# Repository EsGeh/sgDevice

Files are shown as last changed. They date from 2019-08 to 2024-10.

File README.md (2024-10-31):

# sgDevice

*sgDevice* is a MIDI interface that can send and receive MIDI messages to/from a computer via USB.
It has a knobs, switches and triggers. The state of these controls is reported to the connected computer.
It may therefore be used as an input device to control *any kind* of software that receives MIDI messages - there is no intrinsic audio related functionality.
sgDevice (ver. 2) uses the [Arduino](https://www.arduino.cc/) Mega microprocessor board.

This repository contains:

- Basic information about *sgDevice*, a homemade MIDI device

- A software library for the [puredata](https://puredata.info/) music software that enables puredata patches to react to messages from the sgDevice. This allows a pd patch to e.g. play notes when a trigger is pressed or updating an effect parameter based on a knob position

- Tools and utility scripts to compile and upload the firmware to the sgDevice

## Pictures

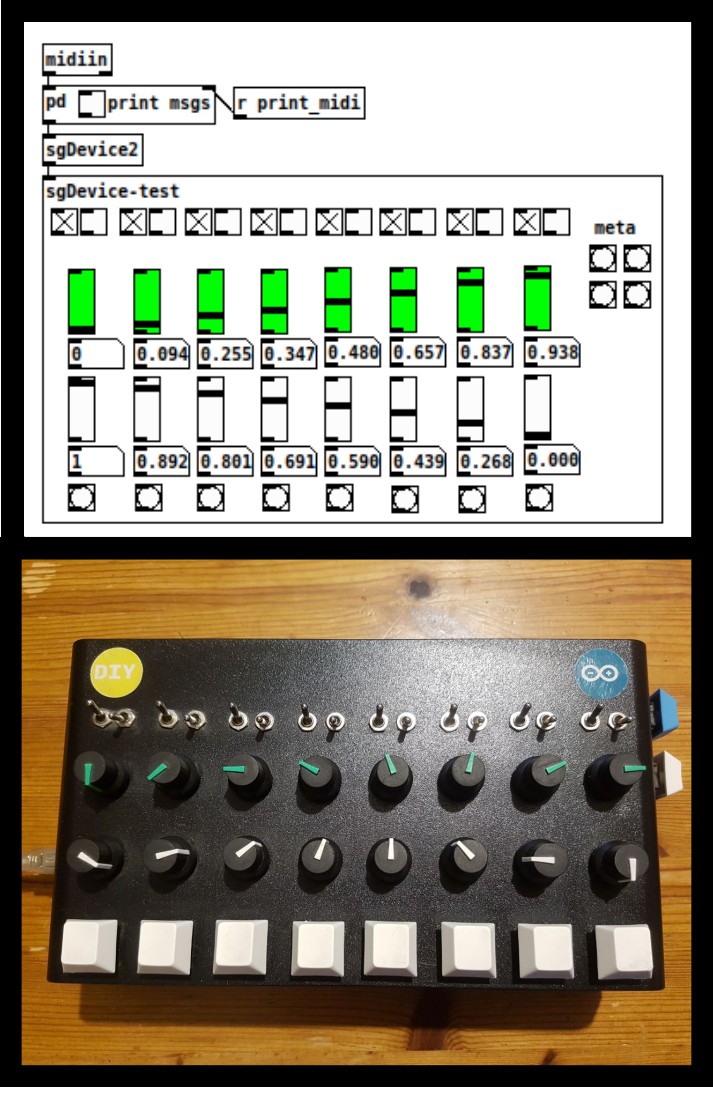
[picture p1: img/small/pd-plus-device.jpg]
pd plus device

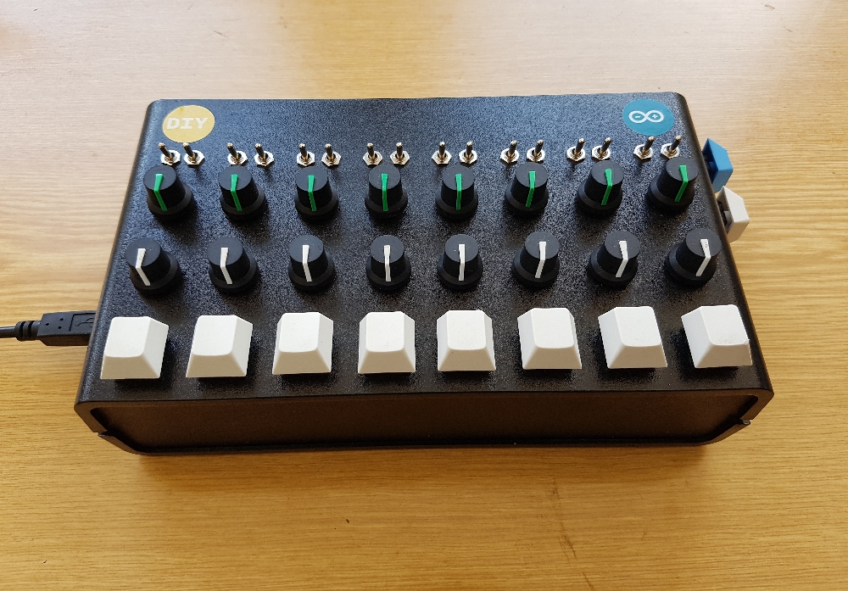
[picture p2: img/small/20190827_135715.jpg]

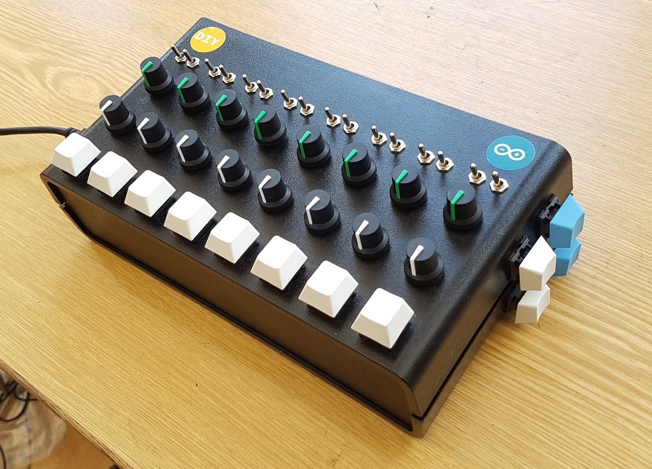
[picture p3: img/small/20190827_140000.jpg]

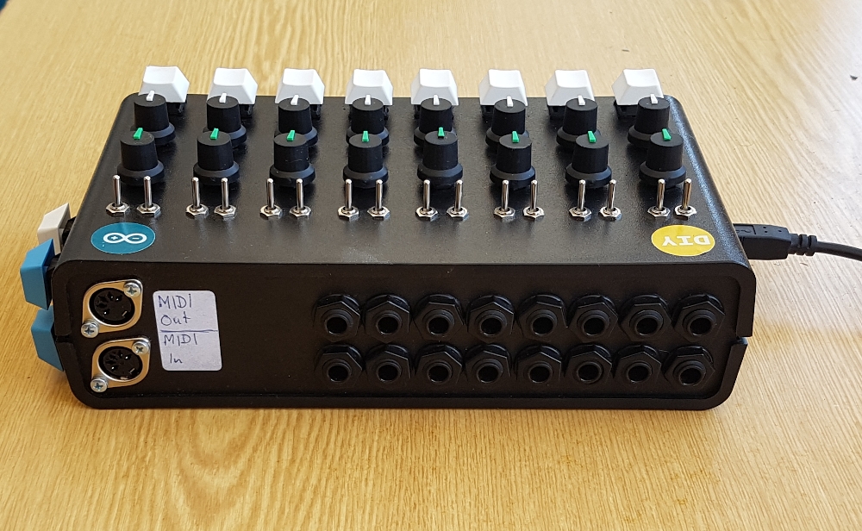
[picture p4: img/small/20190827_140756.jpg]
sgDevice ver 2, backside

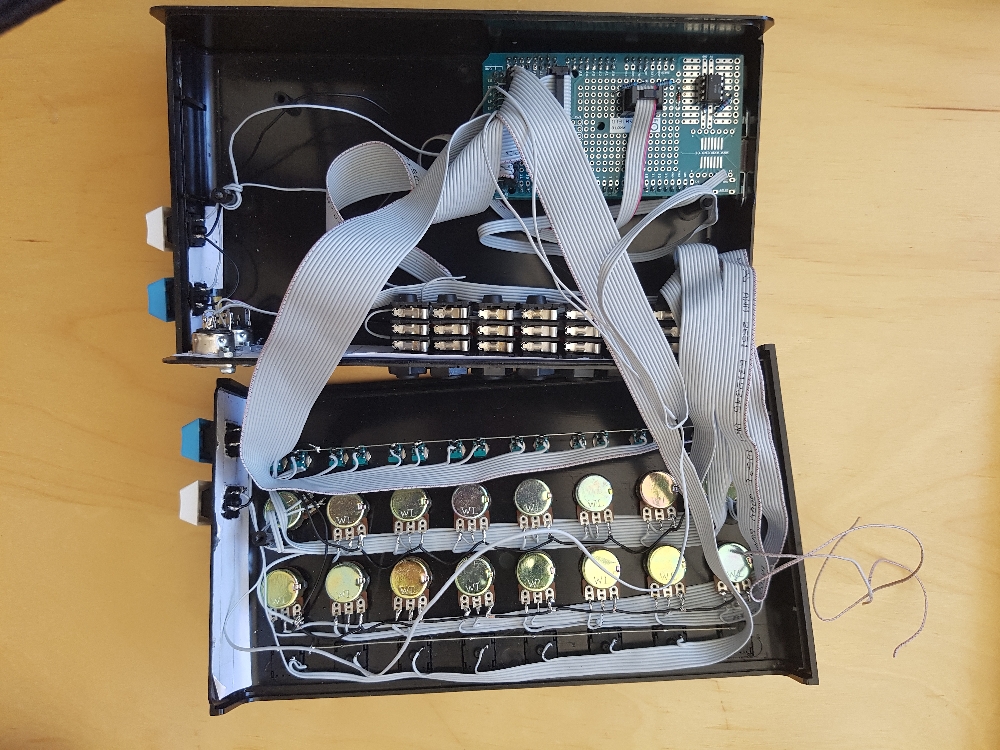
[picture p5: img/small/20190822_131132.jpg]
sgDevice ver 2, interior


## Demos

[Dark Ambient Music with Puredata+sgDevice2](https://youtube.com/watch?v=bEVVliKHZgQ):

Dark Ambient Music with Puredata+sgDevice2 (https://youtube.com/watch?v=bEVVliKHZgQ)

## Prerequisits

- [fish shell](https://fishshell.com/)

## Project setup

- Initialise project (download dependencies, ...):

		$ ./scripts/init.fish
	
	This will download and git dependencies into `./dependencies/`

- Clean project

		$ ./scripts/exit.fish

# Build and upload Firmware

## Build Dependencies

- [arduino-cli](https://github.com/arduino/arduino-cli)
- ( legacy) `arduino`: only for sgDevice1

## sgDevice2

- Turn the Arduino into a native MIDI device:

    The case has to be open in order to set a jumper.
    This (hopefully) has only to be done once!

    plug the device in the PC via USB, then run:

        $ ./scripts/arduino_upload_usb_firmware.fish

    The script will guide you

- Set midi device name:

    plug the device in the PC via USB, then run:

        $ ./scripts/midi_set_device_name.fish

## sgDevice1 (legacy)

Plug the device in the PC via USB, then run:

    $ ./scripts/arduino_upload.fish

The script will guide you

# Build and install the Puredata Library for sgDevice

## Prerequisits

- [puredata](https://puredata.info/): the famous computer music software

## Test locally without installing to system

1. Install library to a local dir

		$ ./scripts/local_init.fish

2. Run Example

		$ ./scripts/local_run.fish

	This opens an example patch documenting the major parts of this library.

3. Uninstall library from the local dir

		$ ./scripts/local_exit.fish

## Installation

- Build and install:

        $ ./scripts/build.fish install

    (for options append `--help`)

- Configure pd to load the library

	start pd and add `structuredDataC` under `File -> Settings -> Start -> New`

- Configure pd to find abstractions

	start pd and add `<install_location>/structuredDataC` under `File -> Settings -> Path -> New`

- Make sure the [dependencies](#dependencies) are installed. Please refer to the corresponding documentation of these libraries.

## Dependencies

- [structuredData](https://github.com/EsGeh/structuredData): Utiliy library for puredata
- [zexy](https://git.iem.at/pd/zexy)

## Documentation

The Documentation is provided as puredata example patches accessible in pd under `Help -> Patch Browser -> structuredDataC`.
Alternatively, for help with a specific object, right click on it and select "help".

# Wiring Schema

sgDevice 2 wiring schema

# Testing and Debugging

## sgDevice2 - Test native Midi Device

	$ ./scripts/local_init.fish
	$ ./scripts/local_run.fish --debug

Check `./logs/` directory afterwards

## sgDevice1 - Test USB input (legacy)

	$ ./scripts/arduino_usbdump.fish

# References

- MIDI Specification:

	- <http://midi.teragonaudio.com/tech/midispec.htm>

- [USBMidiKliK](https://github.com/EsGeh/USBMidiKliK.git):

	Turn the Arduino into a native MIDI Device.

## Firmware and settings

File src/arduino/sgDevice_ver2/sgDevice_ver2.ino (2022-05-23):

#include "Constants_ver2.h"

/*
	NOTES:
	Messages from MIDI-IN are directly sent to the pc.
	Messages from PC are directly sent to MIDI-OUT.
*/

//#define DEBUG_PRINT
#ifdef DEBUG_PRINT
#undef PC_RATE
#define PC_RATE 9600
#endif


class Analog
{
	private:
		int analog[ANALOG_COUNT];
	public:
		Analog()
		{
			for(int i=0; i<ANALOG_COUNT; i++)
			{
				//analog[i] = 0;
				analog[i]= analogRead(i);
			}
		};

		void setup()
		{
		}

		// send all current values:
		void sendAll()
		{
			for(int i=0; i<ANALOG_COUNT; i++)
			{
				toPC(i);
			}
		}

		void update()
		{
			for( int i=0; i<ANALOG_COUNT; i++)
			{
				int newVal = analogRead(i);
				if (abs(newVal-analog[i]) >= 2 )
				{
					analog[i]=newVal;
					toPC(i);
				}
			}
		}

		void toPC(int i)
		{
			#ifdef DEBUG_PRINT
				//Serial.println( analog[i] );
				Serial.print( "Analog value [" );
				Serial.print( i );
				Serial.print( "]: " );
				Serial.println( analog[i] );
			#else
				#ifndef ANALOG_DOUBLE_PRECISION
					Serial.write( 0xB0 );
					Serial.write( ANALOG_CONTROL_ID + i );
					Serial.write( analog[i] );
				#else
					byte msb = analog[i] >> 3;
					byte lsb = analog[i] & 0b00000111;
					Serial.write( 0xB0 );
					Serial.write( ANALOG_CONTROL_ID + i);
					Serial.write( msb);
					Serial.write( 0xB0 );
					Serial.write( ANALOG_CONTROL_ID_FINE + i );
					Serial.write( lsb );
				#endif
			#endif
		}
};

class Buttons
{
	// values
	private:
		unsigned int pin0;
		unsigned int count;
		unsigned int control_id;
		boolean invert;
	public:
		boolean* value;
	// methods:
	public:
		Buttons(
			const unsigned int pin0,
			const unsigned int count,
			const unsigned int control_id,
			const bool invert = false
		)
			:pin0(pin0),
			count(count),
			control_id(control_id),
			value(NULL),
			invert(invert)
		{
			value = new boolean[count];
			for (int i=0; i<count ; i++)
			{
				value[i]=false;
			}
		}
		~Buttons() {
			delete[] value;
		}
		void setup()
		{
			for( int i=0; i<count; i++ )
			{
				pinMode(pin0+i, INPUT_PULLUP);
			}
		}
		// overwrite:
		void OnChange(const unsigned int index, boolean newValue) { }
		void update()
		{
			for (int i=0; i< count ; i++)
			{
				bool new_val = digitalRead(pin0+i);
				bool logical_value =
					(!invert) ? new_val : (!new_val);
				if( logical_value != value[i])
				{
					value[i] = logical_value;
					#ifdef DEBUG_PRINT
						Serial.println(String("Buttons[") + String(pin0+i) + String("] = ") + String((unsigned int )logical_value));
					#else
						Serial.write( 0xB0 );
						Serial.write( control_id + i );
						Serial.write( ((byte )127) * ((byte )logical_value));
					#endif
				}
			}
		}
};

class Midi
{
	private:
		byte buf[6];
		int buf_count;
	public:
	Midi()
		: buf_count(0)
	{
	}

	void setup()
	{
	}

	// MIDI-In -> PC
	void update_midi_in()
	{
		int input = -1;
		if( Serial1.available() > 0 ) {
			input = Serial1.read();
			if( input >= 0x80 ) {
			// status byte:
				// only send "note on" or "note off" msgs
				// (ignore others):
				byte msg_type = input >> 4;
				byte channel = input & 0b00001111;
				if(
					 msg_type == 0x8
					 || msg_type == 0x9
				)
				{
					// increase channel:
					buf[0] = input;
					buf_count = 1;
				}
				else
				{
					// ignore:
					buf_count = 0;
				}
			}
			else
			// data byte:
			{
				if( buf_count > 0 && buf_count < 3 )
				{
					buf[buf_count] = input;
					buf_count ++;
				}
				if( buf_count >= 3 )
				{
					for( int i=0; i<buf_count; i++ )
					{
						Serial.write( buf[i] );
					}
					Serial.flush();
					buf_count = 0;
				}
			}
			/*
			// filter out "timing" and "Active Sensing" input:
			if( input != 0b11111000 && input != 0b11111110 )
			{
				#ifdef DEBUG_PRINT
				//Serial.println( analog[i] );
				Serial.print( "MIDI->PC: " );
				Serial.println( input, HEX);
				#else
				Serial.write( (byte )input );
				Serial.flush();
				#endif
			}
			*/
		}
	}

	// PC -> MIDI-Out
	void update_midi_out()
	{
		int input = -1;
		if( Serial.available() > 0 )
		{
			input = Serial.read();
			#ifdef DEBUG_PRINT
				Serial.print( "PC->MIDI: " );
				Serial.println( input );
				Serial1.write( 0x90 );
				Serial1.write( 60 );
				Serial1.write( 100 );
			#else
				Serial1.write( input );
			#endif
			Serial1.flush();
		}
	}
};

Analog analog;
Midi midi;
Buttons switches(
	PIN_SWITCH,
	SWITCHES_COUNT,
	SWITCHES_CONTROL_ID
);
Buttons triggers(
	PIN_TRIGGERS,
	TRIGGERS_COUNT,
	TRIGGERS_CONTROL_ID,
	true // invert
);
Buttons meta(
	PIN_META,
	META_COUNT,
	META_CONTROL_ID,
	true // invert
);

void setup() {
	Serial.begin(PC_RATE);
	Serial1.begin(MIDI_RATE);

	//sleep(2);

	analog.setup();
	midi.setup();
	switches.setup();
	triggers.setup();
	meta.setup();

	#ifdef DEBUG_PRINT
	Serial.println("initializing");
	#endif
}

//Message

void loop() {
	analog.update();
	midi.update_midi_in();
	midi.update_midi_out();
	switches.update();
	triggers.update();
	meta.update();
}

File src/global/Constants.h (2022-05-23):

#ifndef _CONSTANTS_H_
#define _CONSTANTS_H_


/////////////////////////////
// baud rates:
/////////////////////////////
#define MIDI_RATE 31250
//#define PC_RATE 9600
#define PC_RATE 38400

/////////////////////////////
// control id in MIDI messages:
/////////////////////////////

#define TRIGGERS_CONTROL_ID (32+0)
#define SWITCHES_CONTROL_ID (32+10)
#define ANALOG_CONTROL_ID 20
#define ANALOG_CONTROL_ID_FINE (32+20)
#define META_CONTROL_ID 64

/////////////////////////////
// arduino pins
/////////////////////////////

#define PIN_MIDI_IN 2
#define PIN_MIDI_OUT 3

#define PIN_META_TRIGGER_0 11
#define META_COUNT 2

#define PIN_TRIGGER_OR_SWITCH 10
#define TRIGGERS_COUNT 6
#define SWITCHES_COUNT 6
#define PIN_TOG_0 4

#define TRIGGER_PRESSED 0
#define DEBOUNCE_TIME 200

// which value means
#define TRIGGERS 1


/////////////////////////////
// analog parameters:
/////////////////////////////

#define ANALOG_COUNT 6
#define ANALOG_STEPS 512

// maximum value at analog pins:
#define ANALOG_PIN_BITS 10
#define ANALOG_PIN_RESOLUTION (1<<ANALOG_PIN_BITS)

// if defined: use 2 midi messages to use 14 bytes instead of 7 bytes
// define this, if you want more than ANALOG_STEPS > 128

#define ANALOG_DOUBLE_PRECISION 1

#endif

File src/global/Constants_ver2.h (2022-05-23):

#ifndef _CONSTANTS_H_
#define _CONSTANTS_H_


/////////////////////////////
// baud rates:
/////////////////////////////
#define MIDI_RATE 31250
#define PC_RATE 31250
// (according to MIDI specification)

/////////////////////////////
// control id in MIDI messages:
/////////////////////////////

#define ANALOG_CONTROL_ID 0
#define ANALOG_CONTROL_ID_FINE 32
/* midi control numbers 32..31:
 if ANALOG_DOUBLE_PRECISION is defined,
 these may specify the
 least significant bits (LSB) of
 the controls 0..31.
*/

#define ANALOG_COUNT 16

#define SWITCHES_CONTROL_ID (32+16)
#define SWITCHES_COUNT 16

#define TRIGGERS_CONTROL_ID 64
#define TRIGGERS_COUNT 8

#define META_CONTROL_ID 96
#define META_COUNT 4

/////////////////////////////
// arduino pins
/////////////////////////////

#define PIN_SWITCH 22
#define PIN_TRIGGERS 38
#define PIN_META 46

/////////////////////////////
// analog parameters:
/////////////////////////////

#define ANALOG_MIDI_RES 512
#define ANALOG_STEPS 512

// maximum value at analog pins:
#define ANALOG_PIN_BITS 10
#define ANALOG_PIN_RESOLUTION (1<<ANALOG_PIN_BITS)

// if defined: use 2 midi messages to use 14 bytes instead of 7 bytes.
// uncomment, if you want more than ANALOG_STEPS > 128:
#define ANALOG_DOUBLE_PRECISION

#endif

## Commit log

2019-05-11 dummy code for the new sgDevice2. arduino-cli for compilation, upload.
2019-05-11 added Frizzing draft for hardware implementation of sgDevice version 2
    [sgDevice2.fzz]
2019-06-22 send all controller values, updated schematic (corresp. to hardware)
    [sgDevice2.fzz]
2019-07-04 MIDI firmware: native MIDI device. updated scripts, arduino code, README.
2019-07-05 updated puredata objects and pd doc to work with both device versions
2019-07-25 for sgDevice 2: set midi device name - updated scripts and README
2019-08-22 sgDevice can output midi messages now.
    [sgDevice2.fzz]
2019-08-22 fixed hardware debug mode.
    [sgDevice_ver2.ino]
2019-08-27 added wiring schema to README
    [sgDevice2.fzz]
2019-08-30 fixed segfaults caused by buggy c code. fixed double prec. midi msgs.
    [Constants.h, Constants_ver2.h]
2022-05-22 update and simplify arduino upload script
2022-05-23 finally fixed MIDI input. RTFM!!
    [Constants.h, Constants_ver2.h, sgDevice.ino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]
2022-05-24 fix: meta buttons switch modes in generic GUI
2022-06-02 sgDeviceModes[...].pd: fix switching modes via sgDevice meta buttons
2024-02-27 add picture pd patch plus device
